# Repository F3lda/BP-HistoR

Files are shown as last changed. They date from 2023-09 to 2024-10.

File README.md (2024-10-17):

# BP-HistoR
Embedded system for receiving audio streams on a historic radio receiver

## Abstract
The aim of the work is to create an embedded device on Raspberry Pi or ESP32 platform,
which will allow to play audio streams on historical radios according to their functionality,
either by interfering with their electronics, or by simulating FM and AM broadcasts using
SDR or a created transmitter. The result is a device controlled via a web application allowing
audio streams from SD card, internet, Bluetooth or available FM and DAB broadcasts to
be played on historical radios.

## Result
The result is two versions, one based on a Raspberry Pi using a Software Defined Radio to simulate live radio transmission ([HistoRPi](https://github.com/F3lda/HistoRPi)) and the other based on an ESP32 playing audio through the internal amplifier of a historical radio receiver and controlled by a tuning capacitor ([HistoRinvaz](https://github.com/F3lda/HistoRinvaz)).

### HistoRPi
Video: [https://www.youtube.com/watch?v=wEk9IPGQwg4](https://www.youtube.com/watch?v=wEk9IPGQwg4&list=PLyx6PxqS5pZ5c0ZQkjKCWe2286lkeXFXk)

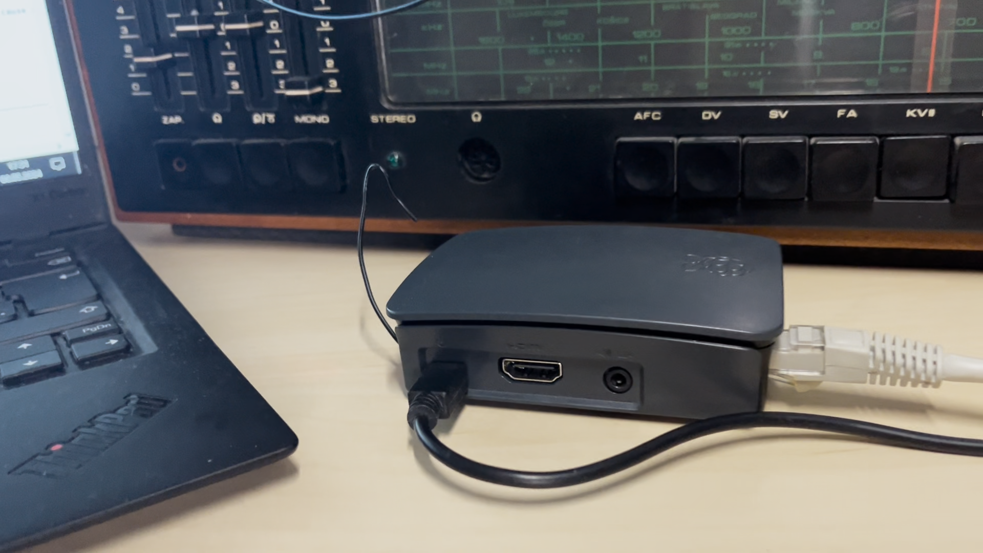
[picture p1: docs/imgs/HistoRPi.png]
HistoRPi


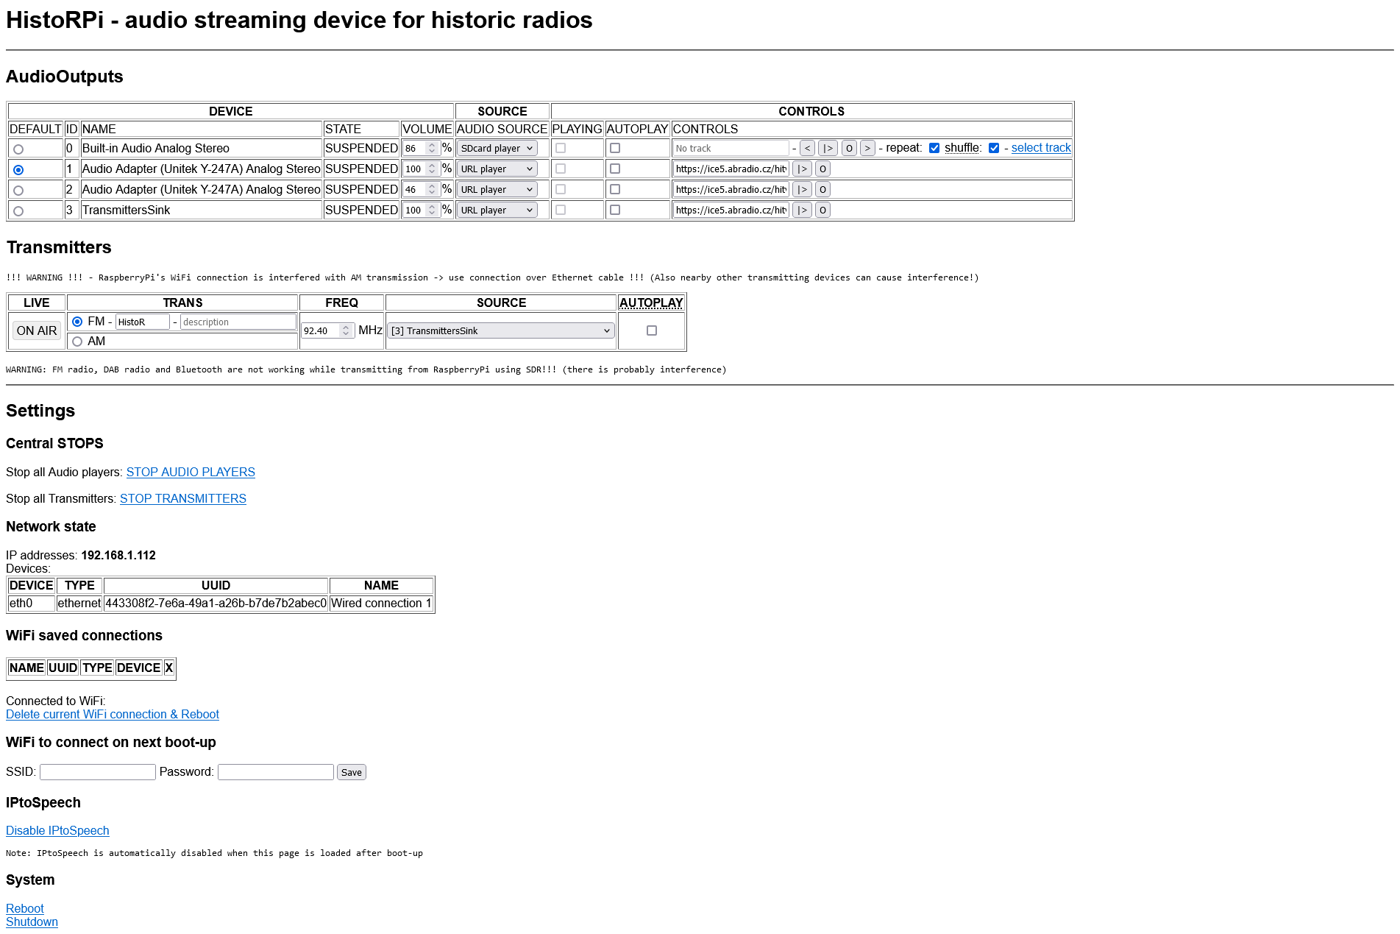
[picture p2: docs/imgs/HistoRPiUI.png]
HistoRPi UI


### HistoRinvaz
Video: [https://www.youtube.com/watch?v=tp0sWiJ3ixc](https://www.youtube.com/watch?v=tp0sWiJ3ixc&list=PLyx6PxqS5pZ5c0ZQkjKCWe2286lkeXFXk)

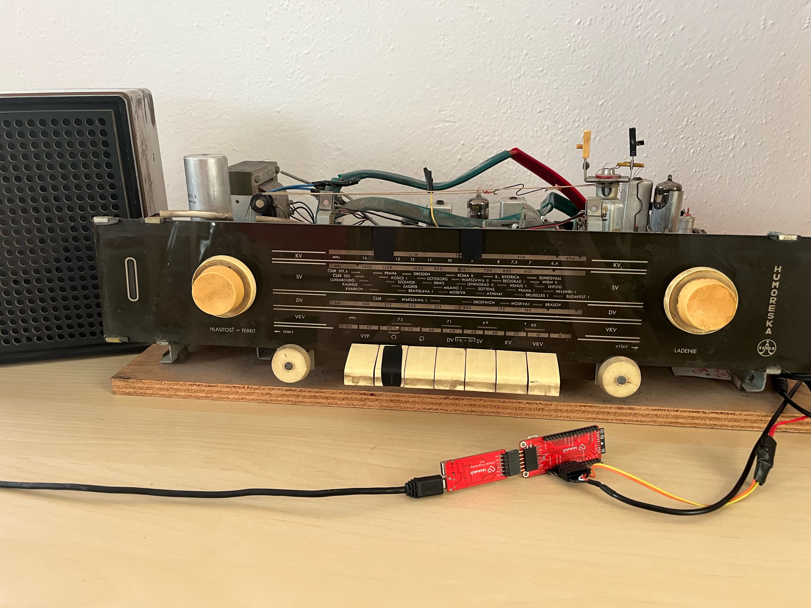
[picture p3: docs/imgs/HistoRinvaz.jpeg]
HistoRinvaz


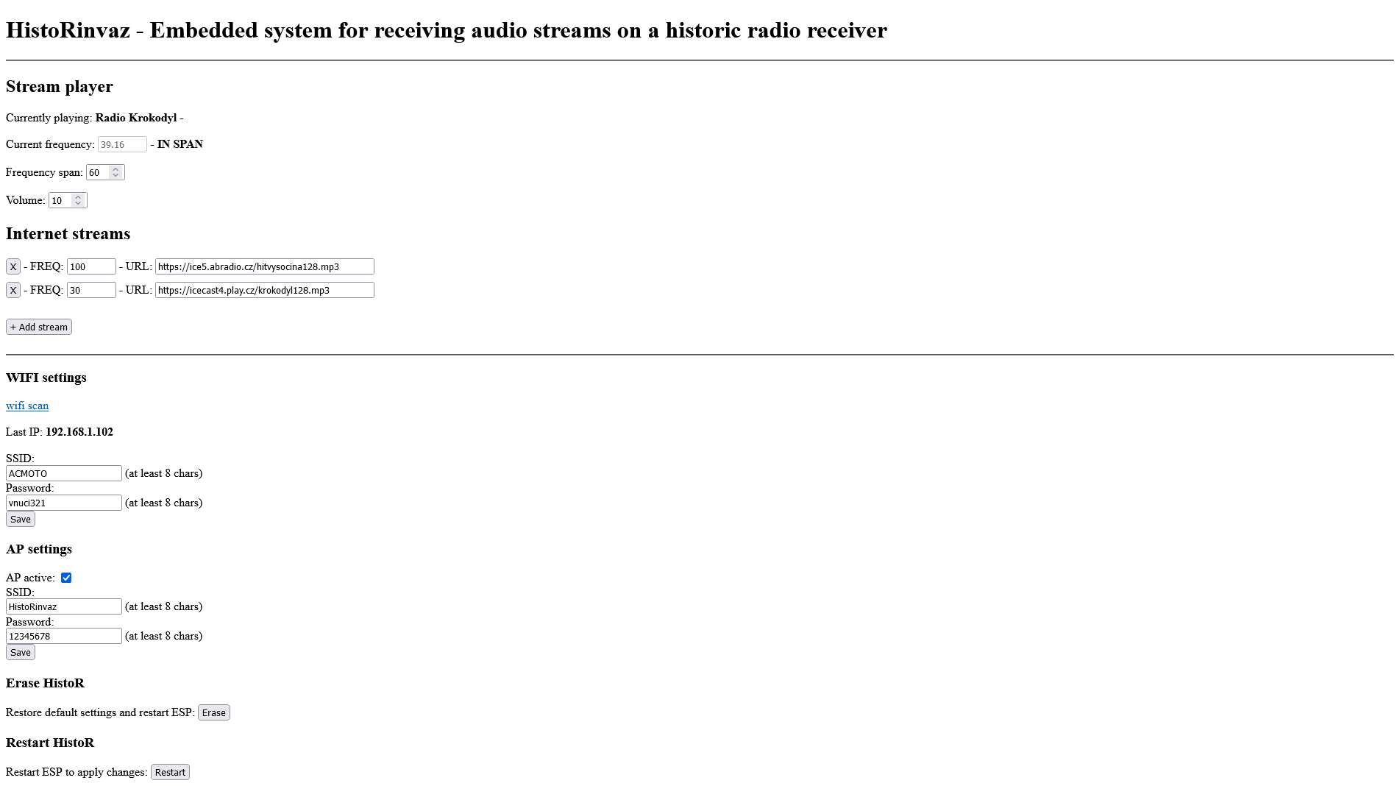
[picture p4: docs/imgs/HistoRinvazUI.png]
HistoRinvaz UI


## Installation
Select the desired version in the release directory and read the README.
[HistoRPi](./release/HistoRPi)
[HistoRinvaz](./release/HistoRinvaz)

## Notes
Further information can be found in the docs.
[HistoR PDF](./docs/FIT_BUT_thesis_2024.pdf)

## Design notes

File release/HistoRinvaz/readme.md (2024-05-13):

# HistoRinvaz
Invasive ESP32-based solution for playing Internet audio streams on vintage radios. Audio stream selection is done by connecting the ESP32 to the radio's tuning capacitor. Playback is done with an internal DAC converter.

## Installation
1. Connect ESP32 pins 32 and 33 to the tuning capacitor disconnected from the vintage radio electronics.
2. Connect pins 25 (right), 26 (left) and GND to the radio's internal or other external speaker.
3. Upload `HistoRinvaz.ino.esp32.bin` binary or source code with `HistoRinvaz.ino` root file via Arduino IDE (version 1.8.13 used) using Partition Scheme `Huge APP` to ESP32.

## Start
- Connect to the ESP32 via a browser by entering its IP address or via its Wi-Fi hotspot.
- Add your URL audio streams at different tuning capacitor values.
- Listen!

## Video
[https://www.youtube.com/watch?v=tp0sWiJ3ixc](https://www.youtube.com/watch?v=tp0sWiJ3ixc&list=PLyx6PxqS5pZ5c0ZQkjKCWe2286lkeXFXk)

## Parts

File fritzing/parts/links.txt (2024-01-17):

FRITZING
https://github.com/Atsumitsu/fritzing-parts/tree/master
https://forum.fritzing.org/t/16x2-i2c-lcd-part/2041/5
https://github.com/adafruit/Fritzing-Library/blob/master/parts/Adafruit%20Si4713%20Stereo%20FM%20Transmitter.fzpz
https://github.com/adafruit/Fritzing-Library/blob/master/parts/Adafruit%20Si5351A%20Clock%20Generator.fzpz
https://forum.fritzing.org/t/step-up-module-mt3608-adjustable-step-up-boost-dc-2a-2v-24v-to-5v-28v/21687/4
https://forum.fritzing.org/uploads/short-url/mPA0Y1CxdUi9kcJkSqXvBOc5KKw.fzpz
https://forum.fritzing.org/t/creating-parts-with-movable-schematic-elements/2121/36

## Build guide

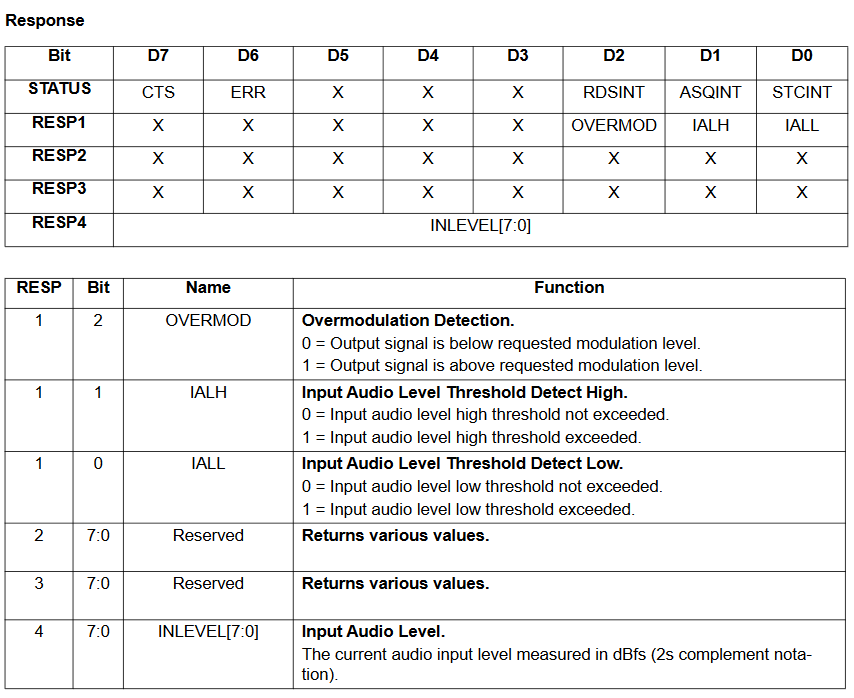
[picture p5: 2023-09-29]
src/BP_M2/FMtransmitter/Screenshot 2023-09-24 at 11-28-14 AN332 Si47xx Programming Guide - AN332.pdf.png

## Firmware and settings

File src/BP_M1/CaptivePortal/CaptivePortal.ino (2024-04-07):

#include <WiFi.h> // https://espressif-docs.readthedocs-hosted.com/projects/arduino-esp32/en/latest/api/wifi.html
#include <DNSServer.h>
#include <WebServer.h>

#include <Preferences.h> // https://randomnerdtutorials.com/esp32-save-data-permanently-preferences/

#include <SPI.h>
#include <SD.h>
#include <FS.h>
#include <SPIFFS.h>

#include "HistoRWebPages.h"

#include "AudioTask.h"


#define BP_ESP_SLAVE_ID 8

#define SDCARD_MAX_PATH_LENGTH 256



// SD card - Digital I/O used
#define SD_CS          5
#define SPI_MOSI      19
#define SPI_MISO      23
#define SPI_SCK       18



const char AppName[] = "HistoR";

Preferences preferences;




// knihovny pro LCD přes I2C
#include <Wire.h>
#include <LiquidCrystal_I2C.h>

// nastavení adresy I2C (0x27 v mém případě),
// a dále počtu znaků a řádků LCD, zde 20x4
LiquidCrystal_I2C lcd(0x27, 16, 2); // SDA -> D21; SCL -> D22; VCC -> VIN (5V)
//https://randomnerdtutorials.com/esp32-i2c-communication-arduino-ide/



/* WIFI */
IPAddress         apIP(10, 10, 10, 1);      // Private network for server
IPAddress         netMsk(255, 255, 255, 0); // Net Mask
WebServer         webServer(80);            // HTTP server
const byte        DNS_PORT = 53;            // Capture DNS requests on port 53
DNSServer         dnsServer;                // Create the DNS object

char WIFIssid[64] = "ACMOTO";
char WIFIpassword[64] = "vnuci321";

char APssid[64] = "HistoR"; // default = AppName
char APpassword[64] = "12345678";

bool APactive = true;

unsigned long WIFIlastConnectTry = 0;
unsigned long WIFIconnectTryNumber = 0;
unsigned int WIFIstatus = WL_IDLE_STATUS;



/* AUDIO */
char AudioCurrentlyPlayingDescription[256] = {0};
char AudioSelectedSource[32] = "MP_SDcard";
char AudioLastPlayedTrack[256] = {0};
bool AudioRandomPlay = false;
bool AudioRepeatAll = false;
bool AudioRepeatOne = false;
char AudioLastInternetURL[256] = {0};
char AudioBluetoothName[256] = {0};
char AudioLastRadioFrequency[8] = {0};
bool AudioAutoPlay = false;
char AudioVolume = 10; // TODO save UI preferences

bool AudioFMtransActive = false;
char AudioFMtransFrequency[8] = {0};
bool AudioAMtransActive = false;
char AudioAMtransFrequency[8] = {0};


bool SDcardAlbumPlaying = false;
char SDcardNextTrackPath[512] = {0};
void AudioPlayerSDcardPlayTrack(void *parameter)
{
    SDcardAlbumPlaying = true;

    if(parameter != NULL){
        strcpy(SDcardNextTrackPath, (const char *)parameter);
    } else {
        //delay(3000);
    }
    Serial.print("Music player: Playing new track: ");
    Serial.println(SDcardNextTrackPath);

    audioStopSong();
    audioConnecttoSD(SDcardNextTrackPath);

    strcpy(AudioSelectedSource, "MP_SDcard"); // set SDcard audio source
    strcpy(AudioLastPlayedTrack, SDcardNextTrackPath);
    strcpy(AudioCurrentlyPlayingDescription, SDcardNextTrackPath);

    preferences.begin("my-app", false);
    preferences.putBytes("AU_SOURCE", AudioSelectedSource, 32);
    preferences.putBytes("AU_LAST_TRACK", AudioLastPlayedTrack, 255);
    preferences.end();

    SDcardNextTrackPath[0] = '\0';
}




/* AUDIO TASK */
char AudioArtist[128] = {0};
char AudioTitle[128] = {0};
void audio_id3data(const char *info){  //id3 metadata
    Serial.print("id3data     ");Serial.println(info); // audio file Artist: ; Title: ;
    char *data = strchr(info, ' ');
    if (data != NULL) {
        data++;
        if (info[0] == 'A' && info[1] == 'r' && info[2] == 't' && data-info == 8) {
            strncpy(AudioArtist, data, 127); Serial.print("Artist=");Serial.println(data);
        }
        if (info[0] == 'T' && info[1] == 'i' && info[2] == 't' && data-info == 7) {
            strncpy(AudioTitle, data, 127); Serial.print("Title=");Serial.println(data);
        }
    }
}
void audio_showstation(const char *info){
    Serial.print("station     ");Serial.println(info);// radio station
    strncpy(AudioArtist, info, 127);
}
void audio_showstreamtitle(const char *info){
    Serial.print("streamtitle ");Serial.println(info);// radio info
    strncpy(AudioTitle, info, 127);
}
void AudioPlayerSDcardFindTrack(fs::FS &fs, const char * dirname, const char * filename){

    Serial.print("AudioPlayerSDcardFindTrack() is running on core ");
    Serial.println(xPortGetCoreID());

    Serial.printf("Listing directory: %s\n", dirname);

    File root = fs.open(dirname);
    if(!root){
        Serial.println("Failed to open directory");
        return;
    }
    if(!root.isDirectory()){
        Serial.println("Not a directory");
        return;
    }

    bool lastTrackFound = false;

    File file = root.openNextFile();
    while(file){

        if(file.isDirectory()){
            Serial.print("  DIR : ");
            Serial.println(file.name());
        } else {
            Serial.print("  FILE: ");
            Serial.print(file.name());
            Serial.print("  SIZE: ");
            Serial.println(file.size());

            if(lastTrackFound == true) {
                strcpy(SDcardNextTrackPath, dirname);
                strcat(SDcardNextTrackPath, "/");
                strcat(SDcardNextTrackPath, file.name());
                root.close();
                return;
            }
            if(strcmp(filename, file.name()) == 0 && lastTrackFound == false) {
                lastTrackFound = true;
            }
        }
        file = root.openNextFile();
    }

    SDcardAlbumPlaying = false;
    Serial.println("Music player: end of album/folder!");

    root.close();
}
void audio_eof_mp3(const char *info){  //end of file
    Serial.print("eof_mp3     ");Serial.println(info);
    Serial.print("eof_mp3() is running on core ");
    Serial.println(xPortGetCoreID());

    Serial.print("SDcardAlbumPlaying: ");
    Serial.println(SDcardAlbumPlaying);

    if(SDcardAlbumPlaying == true) {//audioisrunning == false &&
        char AudioLastPlayedSDcardNextTrackPath[256] = {0};
        strcpy(AudioLastPlayedSDcardNextTrackPath, AudioLastPlayedTrack);
        int i = strlen(AudioLastPlayedSDcardNextTrackPath);
        for(; i > 0; i--) {
            if(AudioLastPlayedSDcardNextTrackPath[i] == '/') {
                AudioLastPlayedSDcardNextTrackPath[i] = '\0';
                i = -1;
            }
        }
        if(i == 0) {
            AudioLastPlayedSDcardNextTrackPath[1] = '\0';
        }

        AudioPlayerSDcardFindTrack(SD, AudioLastPlayedSDcardNextTrackPath, info);
    }

}
void audioStartStop(bool audioisrunning){
    Serial.print("audioisrunning    ");Serial.println(audioisrunning);
    Serial.print("audioStartStop() is running on core ");
    Serial.println(xPortGetCoreID());
}
/* AUDIO TASK - end */


bool AudioPlayerCreateDescription() {
    if (strcmp(AudioSelectedSource, "MP_SDcard") == 0 || strcmp(AudioSelectedSource, "MP_Internet") == 0) {
        if (AudioArtist[0] != '\0' && AudioTitle[0] != '\0') {
            strcpy(AudioCurrentlyPlayingDescription, AudioArtist);
            strcat(AudioCurrentlyPlayingDescription, " - ");
            strcat(AudioCurrentlyPlayingDescription, AudioTitle);
            strcpy(AudioArtist, "");
            strcpy(AudioTitle, "");
        } else if (strcmp(AudioCurrentlyPlayingDescription, "SDcard          ") != 0 && strcmp(AudioSelectedSource, "MP_SDcard") == 0 && SDcardAlbumPlaying == false) {
            strcpy(AudioCurrentlyPlayingDescription, "SDcard          "); // spaces because of LCD display
        } else {
            return false;
        }
    } else if(strcmp(AudioSelectedSource, "MP_Bluetooth") == 0) {
        if (strcmp(AudioCurrentlyPlayingDescription, "Bluetooth       ") != 0) {
            strcpy(AudioCurrentlyPlayingDescription, "Bluetooth       "); // spaces because of LCD display
        } else {
            return false;
        }
    } else if(strcmp(AudioSelectedSource, "MP_Radio") == 0) {
        if (strcmp(AudioCurrentlyPlayingDescription, "Radio           ") != 0) {
            strcpy(AudioCurrentlyPlayingDescription, "Radio           "); // spaces because of LCD display
        } else {
            return false;
        }
    }
    // replace double quotes for javascript
    for(int i = 0; i < strlen(AudioCurrentlyPlayingDescription); i++){
        if (AudioCurrentlyPlayingDescription[i] == '"'){
            AudioCurrentlyPlayingDescription[i] = '\'';
        }
    }
    // save to preferences
    preferences.begin("my-app", false);
    preferences.putBytes("AU_DESCRIPTION", AudioCurrentlyPlayingDescription, 256);
    preferences.end();
    return true;
}

void AudioPlayerStopAllSources() {
    // Stop SDcard + Internet
    SDcardAlbumPlaying = false;
    audioStopSong();
    // Stop Bluetooth
    Wire.beginTransmission(BP_ESP_SLAVE_ID);
    Wire.write(0);
    Wire.write(0);
    Wire.write("BO");
    Wire.write(0);
    Wire.endTransmission();
    // Stop radio
    //TODO
}



#define WEBSERVER_SEND_BUFFER_SIZE 512
char WebserverSendBuffer[WEBSERVER_SEND_BUFFER_SIZE] = {0};
int WebserverSendBufferLength = 0;
void webServer_bufferContentFlush()
{
    webServer_bufferContentAddChar("");
}

void webServer_bufferContentAddChar(const char value[])
{
    int value_length = strlen(value);
    if (WebserverSendBufferLength + value_length >= WEBSERVER_SEND_BUFFER_SIZE || value[0] == '\0') {
        webServer.sendContent(WebserverSendBuffer);
        WebserverSendBuffer[0] = '\0';
        WebserverSendBufferLength = 0;
    }
    WebserverSendBufferLength += value_length;
    strcat(WebserverSendBuffer, value);
    WebserverSendBuffer[WebserverSendBufferLength] = '\0';
}

void webServer_bufferContentAddInt(int value)
{
    char intvalue[32] = {0};
    sprintf(intvalue, "%d", value);
    webServer_bufferContentAddChar(intvalue);
}

void webServer_bufferContentAddJavascriptSetElementChecked(const char elementId[])
{
    webServer_bufferContentAddChar("document.getElementById('");
    webServer_bufferContentAddChar(elementId);
    webServer_bufferContentAddChar("').checked = true;\n");
}

void webServer_bufferContentAddJavascriptSetElementValue(const char elementId[], char value[])
{
    webServer_bufferContentAddChar("document.getElementById('");
    webServer_bufferContentAddChar(elementId);
    webServer_bufferContentAddChar("').value = \"");
    webServer_bufferContentAddChar(value);
    webServer_bufferContentAddChar("\";\n");
}

String webServer_getArgValue(String argname)
{
    for (int i=0; i < webServer.args(); i++) {
        if (webServer.argName(i) == argname){
            return webServer.arg(i);
        }
    }
    return "";
}

void WebServerPrintArgs()
{
      String message = "Number of args received:";
      message += webServer.args();            //Get number of parameters
      message += "\n";                            //Add a new line

      for (int i = 0; i < webServer.args(); i++) {

          message += "Arg n#" + (String)i + " –> ";   //Include the current iteration value
          message += webServer.argName(i) + ": ";     //Get the name of the parameter
          message += webServer.arg(i) + "\n";              //Get the value of the parameter

      }
      Serial.println(message);
}

void WebserverListDir(fs::FS &fs, const char * dirname)
{
    Serial.print("listDir() is running on core ");
    Serial.println(xPortGetCoreID());


    webServer_bufferContentAddChar("<!DOCTYPE html><html><head><title>HistoR - Music player - select track</title></head><body>");


    Serial.printf("Listing directory: %s\n", dirname);
    webServer_bufferContentAddChar("Listing directory: ");
    webServer_bufferContentAddChar(dirname);
    webServer_bufferContentAddChar("\n");

    File root = fs.open(dirname);
    if(!root){
        Serial.println("Failed to open directory");
        webServer_bufferContentAddChar("Failed to open directory\n");
        webServer_bufferContentFlush();
        return;
    }
    if(!root.isDirectory()){
        Serial.println("Not a directory");
        root.close();
        webServer_bufferContentAddChar("Not a directory\n");
        webServer_bufferContentFlush();
        return;
    }

    webServer_bufferContentAddChar("<table><tr><th>Type</th><th>Name</th><th>Size</th></tr>\n");

    if(dirname[0] == '/' && dirname[1] != '\0'){
        int slen = strlen(dirname);
        char stemp[slen+1] = {0};
        strcpy(stemp, dirname);
        int i = slen;
        for(; i > 0; i--) {
            if(stemp[i] == '/') {
                stemp[i] = '\0';
                i = -1;
            }
        }
        if(i == 0) {
            stemp[1] = '\0';
        }
        Serial.print("UP dir: ");
        Serial.println(stemp);
        webServer_bufferContentAddChar("<td><img title=\"Folder\" width=\"20px\" style=\"margin-bottom:-4px\" src=\"./IMG?FOLDER=\" />DIR</td><td><a href='./SDSELECT?PATH=");
        webServer_bufferContentAddChar(stemp);
        webServer_bufferContentAddChar("'>..</a></td><td></td>\n");
    }


    File file = root.openNextFile();
    while(file){
        webServer_bufferContentAddChar("<tr>\n");
        if(file.isDirectory()){
            //Serial.print("  DIR : ");
            webServer_bufferContentAddChar("<td><img title=\"Folder\" width=\"20px\" style=\"margin-bottom:-4px\" src=\"./IMG?FOLDER=\" />DIR</td><td><a href='./SDSELECT?PATH=");
            webServer_bufferContentAddChar(dirname);
            if(dirname[0] == '/' && dirname[1] != '\0'){
                webServer_bufferContentAddChar("/");
            }
            webServer_bufferContentAddChar(file.name());
            webServer_bufferContentAddChar("'>");
            //Serial.println(file.name());
            webServer_bufferContentAddChar(file.name());
            webServer_bufferContentAddChar("</a></td><td></td>\n");
        } else {
            //Serial.print("  FILE: ");
            webServer_bufferContentAddChar("<td><img title=\"File\" width=\"20px\" style=\"margin-bottom:-4px\" src=\"./IMG?DOCUMENT=\" />FILE</td><td><a href='./SDSELECT?PATH=");
            webServer_bufferContentAddChar(dirname);
            webServer_bufferContentAddChar("&PLAY=");
            webServer_bufferContentAddChar(dirname);
            if(dirname[0] == '/' && dirname[1] != '\0'){
                webServer_bufferContentAddChar("/");
            }
            webServer_bufferContentAddChar(file.name());
            webServer_bufferContentAddChar("'>");
            //Serial.print(file.name());
            webServer_bufferContentAddChar(file.name());
            //Serial.print("  SIZE: ");
            webServer_bufferContentAddChar("</a></td><td>");
            //Serial.println(file.size());
            webServer_bufferContentAddInt(file.size());
            webServer_bufferContentAddChar("</td>\n");
        }
        webServer_bufferContentAddChar("</tr>\n");
        file = root.openNextFile();
    }

    root.close();


    webServer_bufferContentAddChar("</table><br><br><a href='./'>close</a>\n");

    webServer_bufferContentAddChar("</body></html>\n");


    webServer_bufferContentFlush();
}



bool isIP(String str) {
  for (int i = 0; i < str.length(); i++) {
    int c = str.charAt(i);
    if (!(c == '.' || (c >= '0' && c <= '9'))) {
      return false;
    }
  }
  return true;
}


bool I2CaddressIsActive(byte address) {
    Wire.begin();
    Wire.beginTransmission(address);
    return !Wire.endTransmission();
}
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
void loop() {
    dnsServer.processNextRequest();
    webServer.handleClient();
    if (WiFi.status() != WL_NO_SHIELD) {
        if (WiFi.status() != WL_CONNECTED && (millis() > (WIFIlastConnectTry + 60000) || WIFIlastConnectTry == 0) && WIFIconnectTryNumber < 2) {
            Serial.println("Connecting to WIFI...");
            WiFi.disconnect();
            WiFi.begin(WIFIssid, WIFIpassword);
            WIFIlastConnectTry = millis();
            WIFIconnectTryNumber++;
            if (WIFIconnectTryNumber == 2) {
                Serial.println("WIFI connection lost/failed!");
                Serial.println("START AP!");
                if (APssid[0] == '\0' || strlen(APssid) < 8) {
                    strcpy(APssid, AppName);
                }
                Serial.println(APssid);
                Serial.println(APpassword);
                WiFi.softAP(APssid, APpassword);
                APactive = true;
                preferences.putBool("APACTIVE", true);

                lcd.setCursor(0, 0);
                lcd.print("AP: ");
                lcd.print(APssid);
            }
        }
        if(WiFi.status() != WIFIstatus){
            WIFIstatus = WiFi.status();
            Serial.println("WIFI status changed: "+String(WIFIstatus));
            if (WIFIstatus == WL_CONNECTED) {
                WIFIconnectTryNumber = 0;
                Serial.println("WL_CONNECTED");
                Serial.println("--------------------");
                Serial.print("Connected to: ");
                Serial.println(WiFi.SSID());
                Serial.print("IP address: ");
                Serial.println(WiFi.localIP());
                Serial.println("--------------------");
                APactive = false;
                preferences.putBool("APACTIVE", false);

                lcd.setCursor(0, 0);
                lcd.print("IP:");
                lcd.print(WiFi.localIP());
            }
        }
    } else {
        Serial.println("WiFi shield not found!");
    }

    if (AudioPlayerCreateDescription()) { // if description changed
        lcd.setCursor(0, 1);
        lcd.print(AudioCurrentlyPlayingDescription);
        lcd.setCursor(0, 0); // TODO check if AP or IP
        if (APactive) {
            lcd.print("AP: ");
            lcd.print(APssid);
        } else {
            lcd.print("IP:");
            lcd.print(WiFi.localIP());
        }
        Serial.println("LCD display");
    }

    if (SDcardNextTrackPath[0] != '\0') { // play next track
        AudioPlayerSDcardPlayTrack(NULL);
    }

    // TODO DISPLAY on CHANGE function -> two vars -> display line1 and line2
    // IP: + IP long -> remove IP:
    // line2 long text -> move text to left
    // replace lcd.print -> lcd_line1 strcpy()



    static unsigned long Timer1000 = 0;
    if ((millis() > (Timer1000 + 1000) || Timer1000 == 0)) {

        // Send
        static byte x = 0;
        Wire.beginTransmission(BP_ESP_SLAVE_ID); // transmit to device #8
        Wire.write("x is ");        // sends five bytes
        Wire.write(x++);              // sends one byte
        Wire.endTransmission();    // stop transmitting

        // Receive
        Wire.requestFrom(BP_ESP_SLAVE_ID, 19);    // request 9 bytes from peripheral device #8
        Serial.print((char)Wire.read());
        Serial.print((char)Wire.read());
        Serial.print((char)Wire.read());
        Serial.print((int)Wire.read()); // "OFF", "ON"
        Serial.print(",");
        Serial.print((int)Wire.read()); // "Disconnected", "Connected"
        Serial.print(",");
        Serial.print((int)Wire.read()); // "Stopped", "Started"
        Serial.print(",");
        Serial.print((int)Wire.read()); // volume (range 0 - 255) (0 - 127)
        Serial.print((char)Wire.read());
        Serial.print((char)Wire.read());
        Serial.print((char)Wire.read());
        Serial.print((int)Wire.read());
        Serial.print(",");
        Serial.print((int)(((int)Wire.read())+900));
        Serial.print(",");
        Serial.print((int)Wire.read());
        Serial.print((char)Wire.read());
        Serial.print((char)Wire.read());
        Serial.print((char)Wire.read());
        Serial.print((char)Wire.read());
        Serial.print((int)Wire.read(), HEX); // FM transmitter status
        Serial.print((char)Wire.read());
        Serial.println();

        Timer1000 = millis();
    }

    yield(); //https://github.com/espressif/arduino-esp32/issues/4348#issuecomment-1463206670
}

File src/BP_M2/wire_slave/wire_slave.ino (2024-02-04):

#include <Wire.h>
#define BP_ESP_SLAVE_ID 8

#include <Si4703_Breakout.h> // FM radio

#include <Adafruit_Si4713.h>// FM transmitter

#include <BluetoothA2DPSink.h> // Bluetooth




/* Bluetooth */
// ==> Example A2DP Receiver which uses connection_state an audio_state callback
//Don’t install the 2.0 version. At the time of writing this tutorial, we recommend using the legacy version (1.8.19) with the ESP32. While version 2 works well with Arduino, there are still some bugs and some features that are not supported yet for the ESP32.
//https://randomnerdtutorials.com/getting-started-with-esp32/

BluetoothA2DPSink a2dp_sink;
bool BTon = false;
char BTname[256] = "MyMusic";
int BTvolume = 127; // 0 - 127

// for esp_a2d_connection_state_t see https://docs.espressif.com/projects/esp-idf/en/latest/esp32/api-reference/bluetooth/esp_a2dp.html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
void connection_state_changed(esp_a2d_connection_state_t state, void *ptr){ // {"Disconnected", "Connecting", "Connected", "Disconnecting"}
    Serial.println(a2dp_sink.to_str(state));
}

// for esp_a2d_audio_state_t see https://docs.espressif.com/projects/esp-idf/en/latest/esp32/api-reference/bluetooth/esp_a2dp.html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
void audio_state_changed(esp_a2d_audio_state_t state, void *ptr){ // {"Suspended", "Stopped", "Started"}
    Serial.println(a2dp_sink.to_str(state));
}

void audio_volume_changed(int volume) {
    Serial.print("Volume: ");
    Serial.println(volume);
    BTvolume = volume;
}






/* FM radio */
#define resetPin 18
#define SDIO 21
#define SCLK 22

Si4703_Breakout radio(resetPin, SDIO, SCLK);
int channel = 0;
int volume = 0;
char rdsBuffer[256] = {0};

void RadioDisplayInfo()
{
    Serial.print("Channel:"); Serial.print(channel);
    Serial.print(" Volume:"); Serial.println(volume);
}





/* FM transmitter */
#define RESETPIN 5
#define FMSTATION 9240      // 10230 == 102.30 MHz
Adafruit_Si4713 FMtrans = Adafruit_Si4713(RESETPIN);
int resetCount = 0;




void setup() {
    Serial.begin(9600);
    while(!Serial);

    // I2C slave setup
    Wire1.setPins(16, 17); // sda, scl
    Wire1.begin(BP_ESP_SLAVE_ID);                // join i2c bus with address #8
    Wire1.onRequest(requestEvent); // register event
    Wire1.onReceive(receiveEvent); // register event


    // Bluetooth setup
    a2dp_sink.set_on_connection_state_changed(connection_state_changed);
    a2dp_sink.set_on_audio_state_changed(audio_state_changed);
    a2dp_sink.set_on_volumechange(audio_volume_changed);
    i2s_pin_config_t my_pin_config = {
      .bck_io_num = 26, // BCK - SCK (CLOCK)
      .ws_io_num = 25, // WS - LCK - LRC (LEFT-RIGHT CLOCK)
      .data_out_num = 27, // DIN (DATA)
      .data_in_num = I2S_PIN_NO_CHANGE
    };
    a2dp_sink.set_pin_config(my_pin_config);



    // Radio setup
    Serial.println("Radio ON!");
    radio.powerOn();
    Serial.println("Volume 0!");
    radio.setVolume(0);



    //FM transmitter
    beginFMtrans();



    Serial.println("ESP slave ON!");
}

void beginFMtrans()
{
    /* FM transmitter */
    if (!FMtrans.begin()) {  // begin with address 0x63 (CS high default)
        Serial.println("Couldn't find FM transmitter?");
    }
    delay(2000);  // maybe needed for initial power???

    // Uncomment to scan power of entire range from 87.5 to 108.0 MHz
    /*
    for (uint16_t f  = 8750; f<10800; f+=10) {
     radio.readTuneMeasure(f);
     Serial.print("Measuring "); Serial.print(f); Serial.print("...");
     radio.readTuneStatus();
     Serial.println(radio.currNoiseLevel);
     }*/


    Serial.print("\nSet TX power");
    FMtrans.setTXpower(115);  // dBuV, 88-115 max

    Serial.print("\nTuning into ");
    Serial.print(FMSTATION/100);
    Serial.print('.');
    Serial.println(FMSTATION % 100);
    FMtrans.tuneFM(FMSTATION); // 102.3 mhz

    // This will tell you the status in case you want to read it from the chip
    FMtrans.readTuneStatus();
    Serial.print("\tCurr freq: ");
    Serial.println(FMtrans.currFreq);
    Serial.print("\tCurr freqdBuV:");
    Serial.println(FMtrans.currdBuV);
    Serial.print("\tCurr ANTcap:");
    Serial.println(FMtrans.currAntCap);

    // begin the RDS/RDBS transmission
    FMtrans.beginRDS();
    FMtrans.setRDSstation((char *)"HistoR"); // max 8 chars
    FMtrans.setRDSbuffer((char *)"HistoRadio FM Live!");
    Serial.println("RDS on!");
}



void loop() {
    // FM transmitter
    Serial.print("Tuned into ");
    Serial.print(FMSTATION/100);
    Serial.print('.');
    Serial.print(FMSTATION % 100);
    Serial.println(" FM");

    FMtrans.readASQ(); // audio signal quality status
    Serial.print("\tCurr ASQ: 0x");
    Serial.print(FMtrans.currASQ, HEX);
    Serial.print(" (");
    printBits(FMtrans.currASQ);
    Serial.println(") [Overmodulation; High Audio; Low Audio] 0 = OK");

    Serial.print("\tCurr InLevel (input audio volume range: from 0 to about -10 (dB)):");
    Serial.println(FMtrans.currInLevel);


    // Restart FM transmitter
    if (FMtrans.currASQ == 0 || FMtrans.currASQ == 255) {
        if (resetCount < 3) {
            resetCount++;
            Serial.println("Restarting FM transmitter...");
            beginFMtrans();
        } else if(resetCount == 3) {
            resetCount++;
            Serial.println("FM transmitter ERROR!");
        }
    } else {
        resetCount = 0;
    }


    delay(3000);
}


void printBits(byte myByte){
    for(byte mask = 0x80; mask; mask >>= 1){
        if(mask & myByte)
            Serial.print('1');
        else
            Serial.print('0');
    }
}




// function that executes whenever data is requested by master
// this function is registered as an event, see setup()
void requestEvent() {
    Wire1.write("bt:"); // Bluetooth
    Wire1.write((byte)BTon); // "OFF", "ON"
    Wire1.write((byte)a2dp_sink.is_connected()); // "Disconnected", "Connected"
    Wire1.write((byte)(a2dp_sink.get_audio_state() == 2)); // "Stopped", "Started"
    Wire1.write((byte)a2dp_sink.get_volume()); // uint8_t (range 0 - 255) (0 - 127)
    Wire1.write(";r:");//10
    Wire1.write((byte)volume);
    Wire1.write((byte)(channel-900));
    Wire1.write((byte)(rdsBuffer[0] != 0));
    Wire1.write(";tr:");//17
    Wire1.write((byte)(FMtrans.currASQ)); // FM transmitter status
    Wire1.write(";");//19
}


void RDSlisten(void * param)
{
    Serial.println("RDS listening");
    radio.readRDS(rdsBuffer, 15000);
    Serial.print("RDS heard:");
    Serial.println(rdsBuffer);
}
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

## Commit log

2023-09-30 I2C communication between ESPs working
2023-10-01 SDcard player and bluetooth fixed
    [CaptivePortal.ino, wire_slave.ino]
2023-10-01 radio added + ESPs communication changed to Wire1
2023-11-10 Bluetooth connection process fixed
    [wire_slave.ino]
2023-11-10 Webserver page loading fixed - buffer is used
    [CaptivePortal.ino]
2023-12-09 added FM trans Status byte and AutoRestart + Restart both ESP32
2023-12-09 AM transmitter + Audio Switch - added
2024-01-15 Fritzing added
    [HistoRdualESP32.fzz]
2024-01-16 Fritzing - MCU5102 schematic fixed
    [HistoRdualESP32.fzz]
2024-01-17 Fritzing HistoRdualESP32 + AMtrans + Display connected
    [HistoRdualESP32.fzz]
2024-01-17 Fritzing HistoResp - AudioSwitcher added
    [HistoRdualESP32.fzz]
2024-01-18 Fritzing - PCB placement + ON/OFF switch and LED added
    [HistoRESP32all.fzz, HistoRdualESP32.fzz]
2024-01-19 Fritzing - dualESP32 inline version added
    [HistoRdualESP32inline.fzz]
2024-01-29 Fritzing - DualESP - PowerBoard added + inline front
    [HistoRdualESP32inline.fzz]
2024-01-30 Fritzing - DualESP - Back finished
    [HistoRdualESP32inline.fzz]
2024-02-04 DualESP own PCB working
    [HistoRdualESP32inline.fzz]
2024-03-16 INVAZver - capacity meter added
2024-03-18 ESP32 capacity meter - added
2024-03-18 ESP32 invaz version - added
2024-04-07 HistoRdualESP - fritzing + small bug fixes
    [HistoRdualESP32inline.fzz]
2024-05-03 fritzing HistoRdualESP - AudioSwitcher + pins on dualESP + AM trans
    [HistoRdualESP32inline.fzz]
